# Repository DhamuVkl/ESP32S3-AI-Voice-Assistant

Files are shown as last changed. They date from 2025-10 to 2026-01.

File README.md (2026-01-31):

# Design your own AI voice assistant 






*A fully custom, open-source AI voice assistant powered by ESP32-S3 and Xiaozhi AI framework*

</div>

---

## 📋 Overview

This project is a complete DIY AI voice assistant built around the ESP32-S3 microcontroller. It combines custom PCB design, advanced audio processing, and cloud-based AI to create a device that rivals commercial smart speakers in functionality while remaining fully open-source and customizable.

Unlike simple voice-controlled devices, this assistant leverages the **Xiaozhi AI framework** to provide natural language understanding through large language models (LLMs) like Qwen, DeepSeek, and GPT. The system uses a hybrid architecture: lightweight tasks run locally on the ESP32-S3, while computationally intensive AI processing happens on cloud servers.

### Key Highlights

- ✨ **Natural Conversation**: Powered by modern LLMs for intelligent, context-aware responses
- 🎙️ **Dual-Microphone Array**: Advanced audio capture with beamforming and echo cancellation
- 🔋 **Battery Powered**: Complete power management with USB-C charging and portable operation
- 💡 **WS2812B LED Ring**: Visual feedback with customizable animations
- 🏠 **Smart Home Ready**: Integration with Home Assistant and other platforms
- 🔧 **Fully Customizable**: Open hardware and software for endless possibilities
- 📱 **Web-Based Control**: Easy configuration through Xiaozhi console
- 🌐 **Multi-Language**: Support for multiple languages depending on AI model

---

## 🎯 Features

### Hardware Features
- **ESP32-S3-WROOM-1-N16R8** (Dual-core, 16MB Flash, 8MB PSRAM)
- **Dual ICS-43434 MEMS Microphones** for superior audio capture
- **MAX98357A I²S Amplifier** driving 3W speaker
- **BQ24250 Li-Ion Charger** with USB-C power delivery
- **MAX20402 Buck-Boost Regulator** for stable 3.3V output
- **WS2812B RGB LED Ring** for visual status indication
- **Optional OLED Display** header for screen integration
- **Compact PCB Design** (2-layer, professionally fabricated)
- **Custom 3D-Printed Enclosure** optimized for acoustics

### Software Features
- **Wake Word Detection** using Espressif's WakeNet
- **Audio Front-End (AFE)** with noise reduction and echo cancellation
- **WebSocket Communication** for low-latency server connection
- **Multiple AI Models** (Qwen, DeepSeek, GPT-4, and more)
- **Conversation History** and context awareness
- **Voice Profile Support** for personalized responses
- **Smart Home Integration** via Xiaozhi skill marketplace
- **OTA Updates** for firmware upgrades
- **Battery Monitoring** with low-battery alerts

---

## 🛠️ Hardware

### Bill of Materials (BOM)

| Component | Part Number | Quantity | Notes |
|---|---|---|---|
| Microcontroller | ESP32-S3-WROOM-1-N16R8 | 1 | Main processor |
| Microphones | TDK InvenSense ICS-43434 | 2 | Digital MEMS |
| Audio Amplifier | MAX98357AETE+ | 1 | Class-D I²S |
| Battery Charger | BQ24250RGER | 1 | Li-Ion charging IC |
| DC-DC Converter | MAX20402ATGA/+ | 1 | Buck-boost regulator |
| RGB LEDs | WS2812B-5050 | 8-12 | Addressable LEDs |
| USB-C Connector | USB4105-GF-A | 1 | Power & programming |
| Speaker | 3W 4Ω Cavity Speaker | 1 | Audio output |
| Battery | Li-Ion/LiPo 3.7V | 1 | 2000-3000mAh recommended |
| Capacitors | Various (0603/0805) | ~25 | See full BOM |
| Resistors | Various (0603) | ~15 | See full BOM |
| Switches | 6x6mm Tactile | 2 | Reset & Boot |
| TVS Diode | USBLC6-2SC6 | 1 | USB ESD protection |

**📥 Full BOM with part numbers**: [Download BOM.csv](Hardware/PCB/BOM/ESP-AI-Assistant-BOM.xlsx)

### PCB Design

The custom PCB is a 2-layer design measuring approximately 80x60mm with careful attention to:
- Signal integrity for I²S audio
- Power distribution with minimal noise
- Thermal management for power ICs
- Acoustic isolation between microphones and speaker

### 3D Enclosure

The enclosure is designed for FDM 3D printing with features for:
- Acoustic optimization (speaker grille, microphone ports)
- LED light diffusion ring
- USB-C and button access
- Battery compartment
- Ventilation slots

## 🚀 Getting Started

### Prerequisites

**Hardware Tools**:
- Soldering iron and supplies
- Multimeter for testing
- USB-C cable (data capable)
- 3D printer (optional, for enclosure)

**Software Requirements**:
- [Visual Studio Code](https://code.visualstudio.com/)
- [ESP-IDF Extension for VS Code](https://marketplace.visualstudio.com/items?itemName=espressif.esp-idf-extension)
- ESP-IDF v5.4 or newer
- Git

### Step 1: Hardware Assembly

1. **Order PCB**: Upload `hardware/gerbers/gerbers.zip` to JLCPCB, PCBWay, or ALLPCB
2. **Source Components**: Use the BOM to order parts from DigiKey, Mouser, or LCSC
3. **Assemble PCB**: Follow the assembly guide for soldering instructions
4. **3D Print Enclosure**: Print the STL files and assemble

### Step 2: WiFi Configuration

On first boot, the device creates a WiFi access point:

1. Connect to WiFi network: `Xioazhi`
2. Navigate to `http://192.168.4.1`
3. Enter your WiFi credentials
4. Device will restart and connect to your network

**Alternative**: Configure WiFi via `idf.py menuconfig` before flashing

### Step 3: Xiaozhi Cloud Setup

1. Create account at [xiaozhi.me](https://xiaozhi.me)
2. Navigate to [Console → Agents](https://xiaozhi.me/console/agents)
3. Click "Add Device" to generate Device ID and Pairing Code
4. Device will auto-pair on first cloud connection
5. Customize AI personality, voice, and skills through console

### Step 4: Test Your Assistant

1. Say the wake word: **"Hey Wanda"**
2. Wait for LED confirmation (blue pulse)
3. Speak your question or command
4. Assistant responds through speaker
5. LED returns to idle state

---

## 🤝 Contributing

Contributions are welcome! Here's how you can help:

### Reporting Bugs
- Use GitHub Issues with detailed reproduction steps
- Include serial monitor logs
- Specify hardware revision and firmware version

### Feature Requests
- Open a GitHub Issue with [Feature Request] tag
- Describe use case and benefits
- Discuss implementation approach

**Contribution Guidelines**: [CONTRIBUTING.md](CONTRIBUTING.md)

---

## 📊 Project Status

- [x] PCB Design and fabrication
- [x] Firmware core functionality
- [x] Xiaozhi cloud integration
- [x] Basic voice interaction
- [x] 3D enclosure design
- [ ] Multi-device mesh networking
- [ ] Offline mode with local LLM
- [ ] Custom wake word training tools
- [ ] Mobile app for configuration
- [ ] Additional language packs

---

## 🔗 Related Projects

- [Xiaozhi ESP32](https://github.com/78/xiaozhi-esp32) - Official Xiaozhi firmware
- [ESP-IDF](https://github.com/espressif/esp-idf) - Espressif IoT Development Framework
- [WakeNet](https://github.com/espressif/esp-sr) - Espressif speech recognition
- [Home Assistant](https://www.home-assistant.io/) - Smart home integration

---

## 📄 License

This project is licensed under the MIT License - see [LICENSE](LICENSE) for details.

### Third-Party Licenses
- ESP-IDF: Apache 2.0
- Xiaozhi Framework: MIT
- Component datasheets: Respective manufacturers

---

## 🙏 Acknowledgments

- **Espressif Systems** for the amazing ESP32-S3 platform and development tools
- **Xiaozhi Team** for creating and maintaining the AI framework
- **Open-source community** for countless libraries and examples
- **PCB manufacturers** (JLCPCB, PCBWay) for affordable prototyping
- **Everyone** who contributed feedback, testing, and improvements

---

**Xiaozhi Community**:
- Forum: [xiaozhi.me/community](https://xiaozhi.me/community)
- Documentation: [docs.xiaozhi.me](https://docs.xiaozhi.me)

<div align="center">

**Built with ❤️ by makers, for makers**

[Documentation](docs/) • [Hardware Files](hardware/) • [Firmware](firmware/) • [Community](https://github.com/yourusername/esp32s3-voice-assistant/discussions)

</div>

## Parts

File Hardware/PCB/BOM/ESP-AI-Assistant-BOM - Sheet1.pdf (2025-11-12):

Value | Manufacturer | DigiKey Part Number | DigiKey Link | Datasheet | Quantity
ESP32-S3-WROOM-1-N16R8 | Espressif Systems | 5407-ESP32-S3-WROOM-1-N16R8CT-ND | https://www.digikey.in/short/5rjqc45t | https://www.espressif.com/sites/default/files/documentation/esp32-s3-wroom-1_wroom-1u_datasheet_en.pdf 1
BQ24250RGER | Texas Instruments | 296-43584-1-ND | https://www.digikey.in/short/8w7dh5rt | https://www.ti.com/general/docs/suppproductinfo.tsp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 1
MAX20402AFLB_VY+T | Analog Devices Inc./Maxim Integrated | 175-MAX20402AFLB/VY+TCT-ND | https://www.digikey.in/short/84zhtbjr | https://www.analog.com/media/en/technical-documentation/data-sheets/max20402-max20403.pdf 1
MAX98357AETE+T | Analog Devices Inc./Maxim Integrated | MAX98357AETE+TCT-ND | https://www.digikey.in/short/v0847d0t | https://datasheets.maximintegrated.com/en/ds/MAX98357A-MAX98357B.pdf 1
ICS-43434 | TDK InvenSense | 1428-1066-1-ND | https://www.digikey.in/short/cprbj7jt | https://invensense.tdk.com/download-pdf/ics-43434-datasheet/ | 2
0.1uF | YAGEO | 311-1088-1-ND | https://www.digikey.in/short/j9bbtzmn | https://www.yageo.com/en/Chart/Download/pdf/CC0603KRX7R7BB104 4
1uF | Samsung Electro-Mechanics | 1276-1946-1-ND | https://www.digikey.in/short/w13tfhpm | https://mm.digikey.com/Volume0/opasdata/d220001/medias/docus/3584/CL10B105KP8NNNC_Spec.pdf 8
2.2uF | Samsung Electro-Mechanics | 1276-1040-1-ND | https://www.digikey.in/short/qzm0rdtn | https://mm.digikey.com/Volume0/opasdata/d220001/medias/docus/421/CL10A225KO8NNNC_Spec.pdf 4
10uF | Samsung Electro-Mechanics | 1276-1038-1-ND | https://www.digikey.in/short/7q939fq1 | https://mm.digikey.com/Volume0/opasdata/d220001/medias/docus/609/CL10A106KQ8NNNC_Spec.pdf 1
22uF | Samsung Electro-Mechanics | 1276-1100-1-ND | https://www.digikey.in/short/4z5qrjnc | https://mm.digikey.com/Volume0/opasdata/d220001/medias/docus/5784/CL21A226MQQNNNE.pdf 2
33nF | Samsung Electro-Mechanics | 1276-2040-1-ND | https://www.digikey.in/short/f324pm0d | https://mm.digikey.com/Volume0/opasdata/d220001/medias/docus/1240/CL10B333KB8NFNC_Spec.pdf 1
220pF | KEMET | 399-C0603C221F5GACAUTOCT-ND | https://www.digikey.in/short/tt3r1fv9 | https://search.kemet.com/download/datasheet/C0603C221F5GACAUTO 2
0R | YAGEO | 311-0.0GRCT-ND | https://www.digikey.in/short/b3v7vpzt | https://www.yageogroup.com/content/datasheet/asset/file/PYU-RC_GROUP_51_ROHS_L 4
33R | Stackpole Electronics Inc | RMCF0603FT33R2CT-ND | https://www.digikey.in/short/jp83p589 | https://www.seielect.com/catalog/SEI-RMCF_RMCP.pdf | 2
249R | Stackpole Electronics Inc | RMCF0603FT249RCT-ND | https://www.digikey.in/short/nwpz5jtp | https://www.seielect.com/catalog/SEI-RMCF_RMCP.pdf | 1
267R | YAGEO | 311-267HRCT-ND | https://www.digikey.in/short/w979pjc4 | https://www.yageogroup.com/content/datasheet/asset/file/PYU-RC_GROUP_51_ROHS_L 1
1K | Stackpole Electronics Inc | RMCF0603FT1K00CT-ND | https://www.digikey.in/short/vnptcw85 | https://www.seielect.com/catalog/SEI-RMCF_RMCP.pdf | 2
1K5 | YAGEO | 311-1.5KGRCT-ND | https://www.digikey.in/short/mz5z44p5 | https://www.yageogroup.com/content/datasheet/asset/file/PYU-RC_GROUP_51_ROHS_L 1
5K1 | YAGEO | 311-5.10KHRCT-ND | https://www.digikey.in/short/f454n338 | https://www.yageogroup.com/content/datasheet/asset/file/PYU-RC_GROUP_51_ROHS_L 2
10K | YAGEO | 311-10.0KHRCT-ND | https://www.digikey.in/short/839tmnrn | https://www.yageogroup.com/content/datasheet/asset/file/PYU-RC_GROUP_51_ROHS_L 5
20K | YAGEO | 311-20.0KHRCT-ND | https://www.digikey.in/short/d0d20fp5 | https://www.yageogroup.com/content/datasheet/asset/file/PYU-RC_GROUP_51_ROHS_L 3
100K | Stackpole Electronics Inc | RMCF0603FT100KCT-ND | https://www.digikey.in/short/ph19q045 | https://www.seielect.com/catalog/SEI-RMCF_RMCP.pdf | 2
274K | Stackpole Electronics Inc | RMCF0603FT274KCT-ND | https://www.digikey.in/short/d8vrz4zz | https://www.seielect.com/catalog/SEI-RMCF_RMCP.pdf | 1
1uH | TDK Corporation | 445-6672-1-ND | https://www.digikey.in/short/hqtv9tb5 | https://mm.digikey.com/Volume0/opasdata/d220001/medias/docus/2091/VLS3015E_Series.pdf 1
1.5uH | Taiyo Yuden | 587-2617-1-ND | https://www.digikey.in/short/4rtp9mqb | https://mm.digikey.com/Volume0/opasdata/d220001/medias/docus/610/NR3015T1R5N_SS.pdf 1
FerriteBead_Small | Eaton - Electronics Division | 283-MFBW1V2012-000-RCT-ND | https://www.digikey.in/short/v80fpmrb | https://www.eaton.com/content/dam/eaton/products/electronic-components/resources/data-sheet/eaton-mfbw1v2012-high-impedance-multilayer-ferrite-chip-bead-data-sheet.p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 2
SLW-66527511-SMT-TR | Same Sky (Formerly CUI Devices) | 2223-SLW-66527511-SMT-TRCT-ND | https://www.digikey.in/short/04nz77qw | https://www.cuidevices.com/product/resource/digikeypdf/slw-66527511-smt-tr.pdf 2
WS2812B RGB LED | XINGLIGHT | 5962-XL-5050RGBC-WS2812BTR-ND | https://www.digikey.in/short/mt8f2cfr | https://mm.digikey.com/Volume0/opasdata/d220001/medias/docus/6472/5962_XL-5050RGBC-WS2812B%20%205050%E5%B9%BB%E5%BD%A9%E9%80%8F%E6%98%8E.pdf 4
LED Red | XINGLIGHT | 5962-XL-1608SURC-06TR-ND | https://www.digikey.in/short/95jnwpf4 | https://mm.digikey.com/Volume0/opasdata/d220001/medias/docus/6472/5962_XL-1608SURC-06%20%20%200603%E7%BA%A20.6T.pdf 1
LED Blue | XINGLIGHT | 5962-XL-1608UBC-04TR-ND | https://www.digikey.in/short/2zmhjvv8 | https://mm.digikey.com/Volume0/opasdata/d220001/medias/docus/6472/5962_XL-1608UBC-04%20%20%200603%E8%93%9D0.4T.pdf 1
Tactile Switch SPST | Omron Electronics Inc-EMC Div | SW1021CT-ND | https://www.digikey.in/short/czjddfbv | https://omronfs.omron.com/en_US/ecb/products/pdf/en-b3u.pdf 2
USB_C Receptacle | GCT | 2073-USB4105-GF-A-060CT-ND | https://www.digikey.in/short/4vnp0cm8 | https://gct.co/files/specs/usb4105-spec.pdf | 1
B2B-PH-K-S | JST Sales America Inc. | 455-1704-ND | https://www.digikey.in/short/793pddq3 | https://www.jst-mfg.com/product/pdf/eng/ePH.pdf | 2
Conn_01x08 | Adam Tech | 2057-2SH-C-08-TS-ND | https://www.digikey.in/short/4q5zwphp | https://app.adam-tech.com/products/download/data_sheet/240572/2sh-c-xx-ts-data-sheet.pdf 1

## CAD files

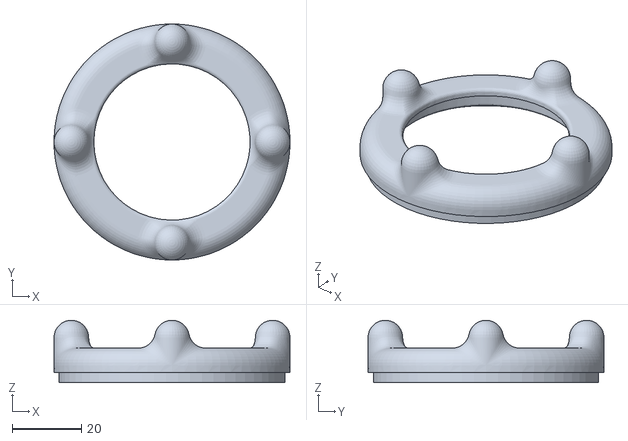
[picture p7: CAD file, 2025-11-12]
Hardware/CAD/Bottom-Enclosure.STL
68.0 x 68.0 x 18.0

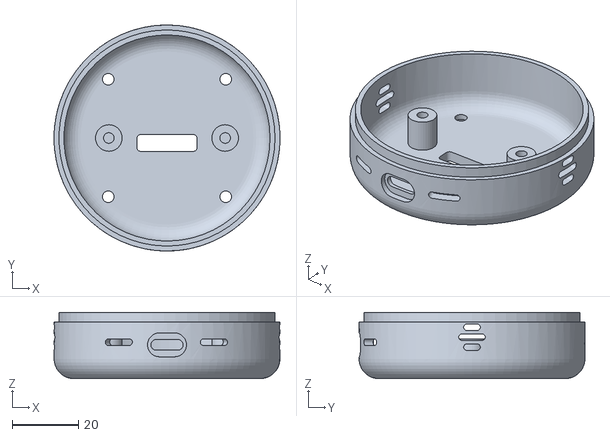
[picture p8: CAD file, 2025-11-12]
Hardware/CAD/Top-Enclosure-Cap.STL
68.0 x 68.0 x 20.0

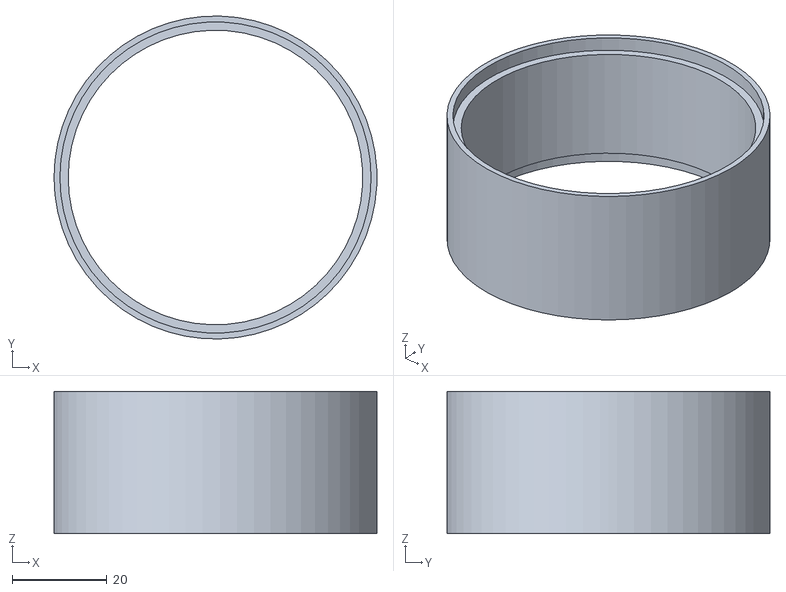
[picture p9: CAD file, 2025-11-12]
Hardware/CAD/Middle-Enclosure.STL
68.0 x 68.0 x 30.0

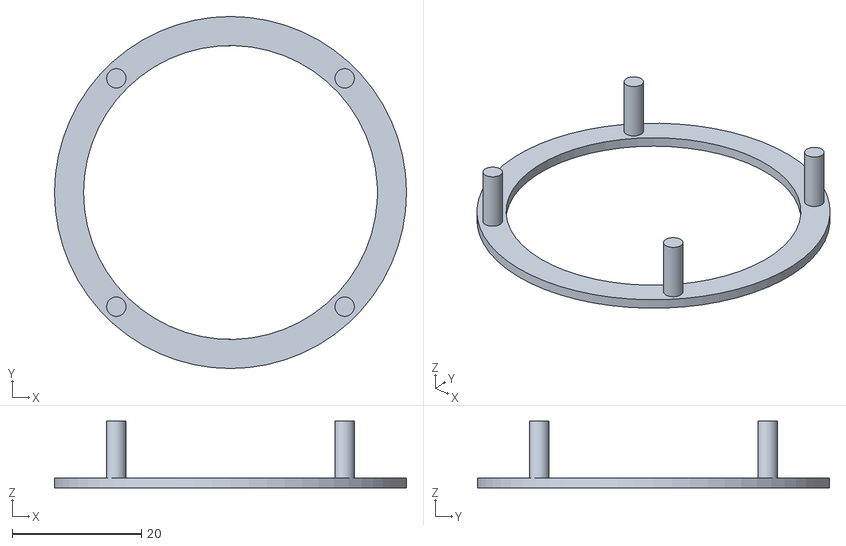
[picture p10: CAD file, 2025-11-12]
Hardware/CAD/Neopixel-Diffuser-Ring.STL
54.5 x 54.5 x 10.3

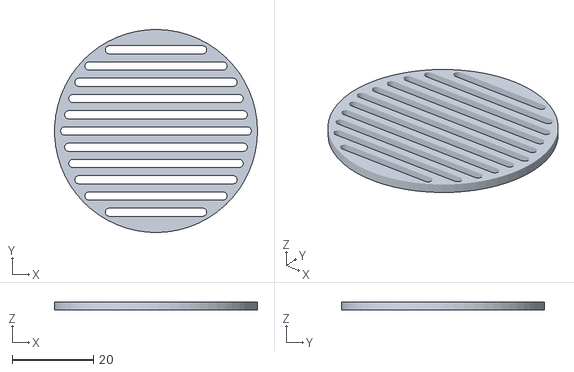
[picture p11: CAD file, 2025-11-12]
Hardware/CAD/Speaker-grill.STL
50.0 x 50.0 x 2.00

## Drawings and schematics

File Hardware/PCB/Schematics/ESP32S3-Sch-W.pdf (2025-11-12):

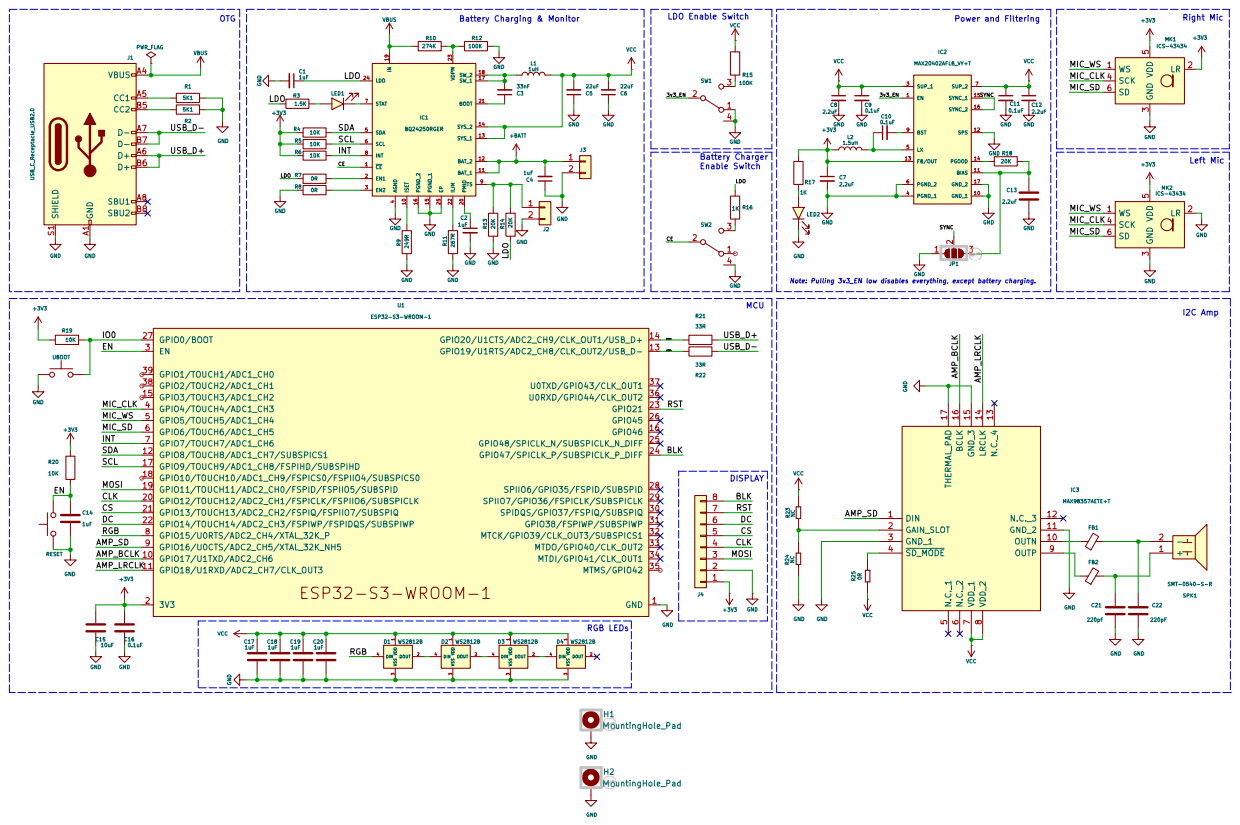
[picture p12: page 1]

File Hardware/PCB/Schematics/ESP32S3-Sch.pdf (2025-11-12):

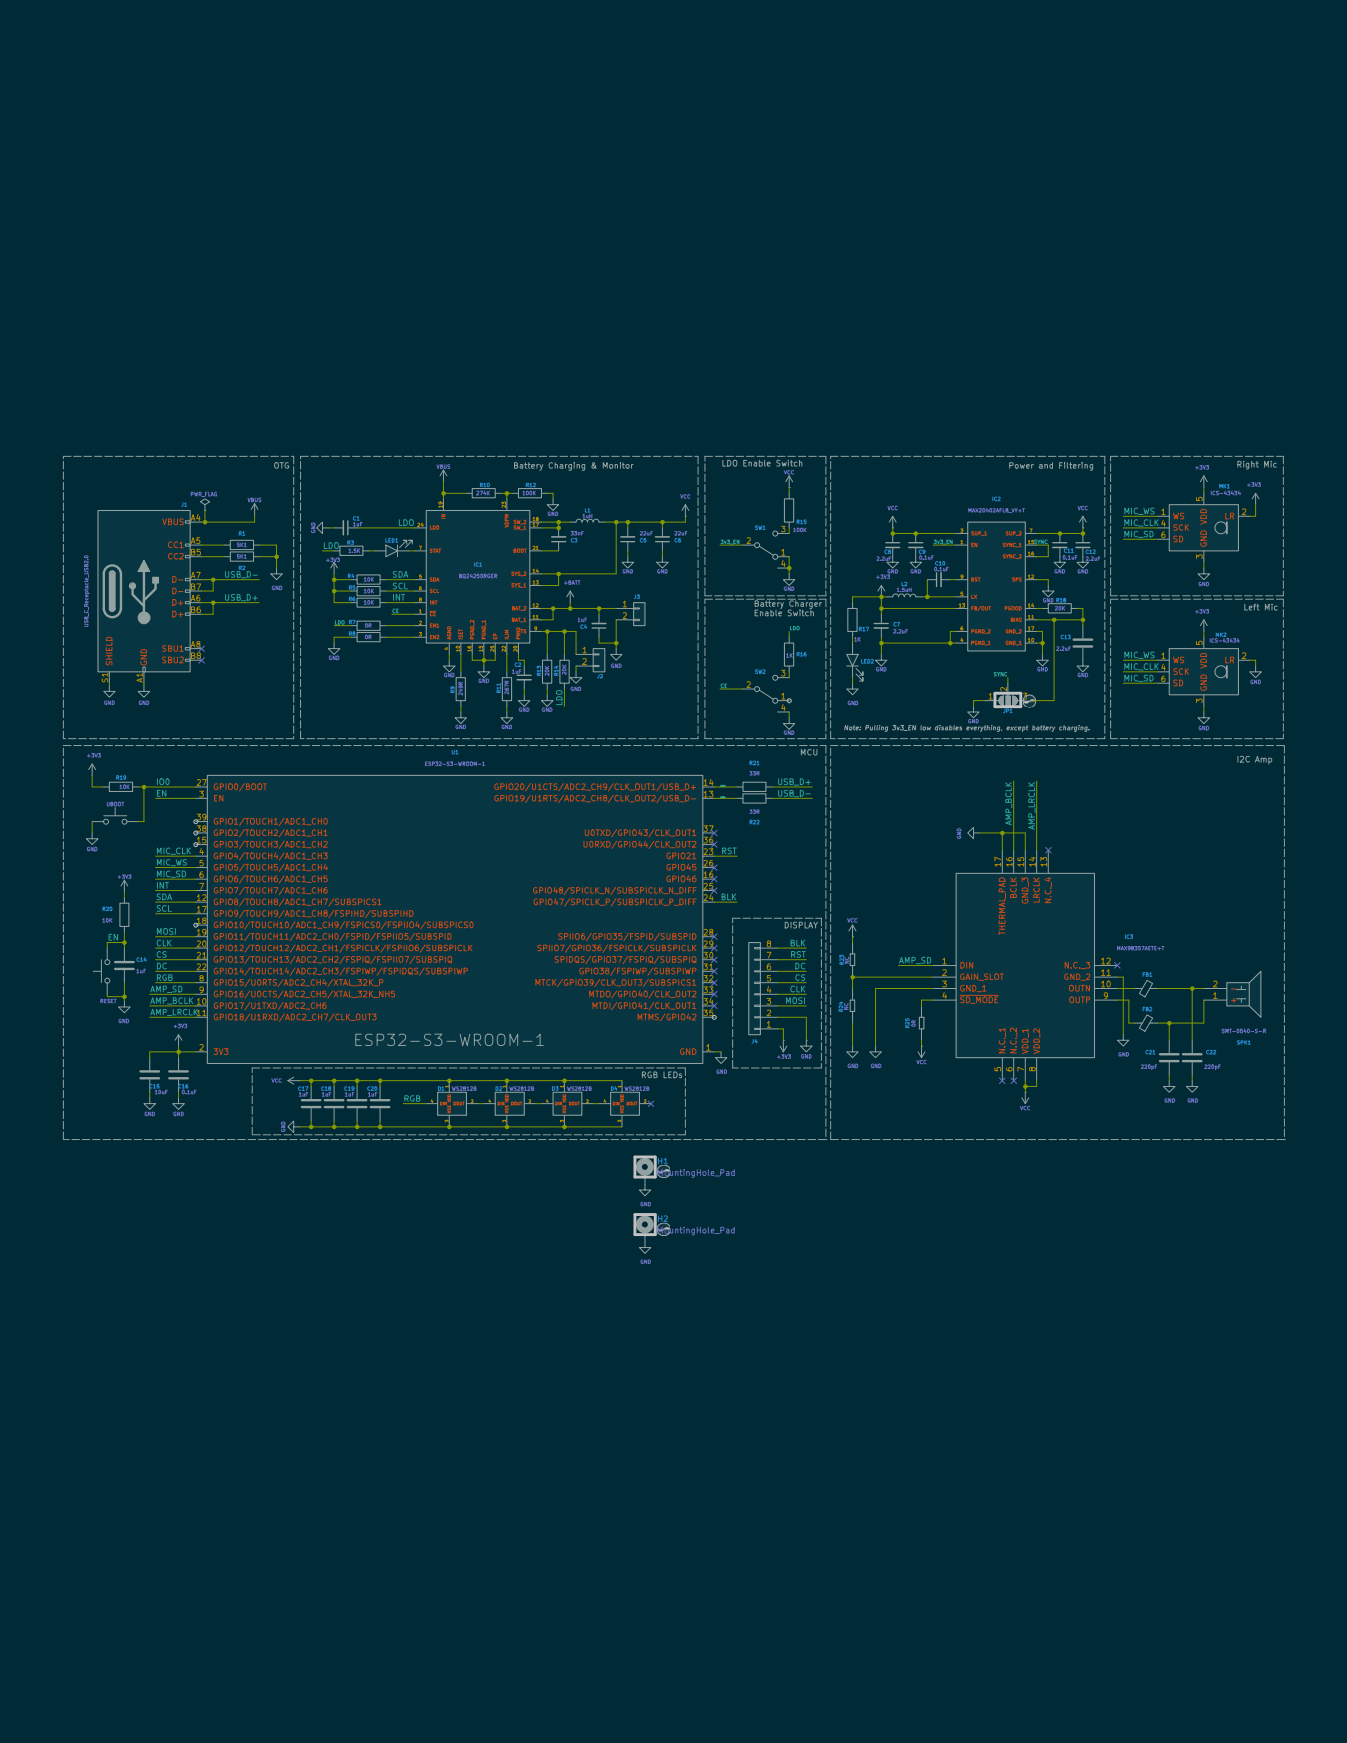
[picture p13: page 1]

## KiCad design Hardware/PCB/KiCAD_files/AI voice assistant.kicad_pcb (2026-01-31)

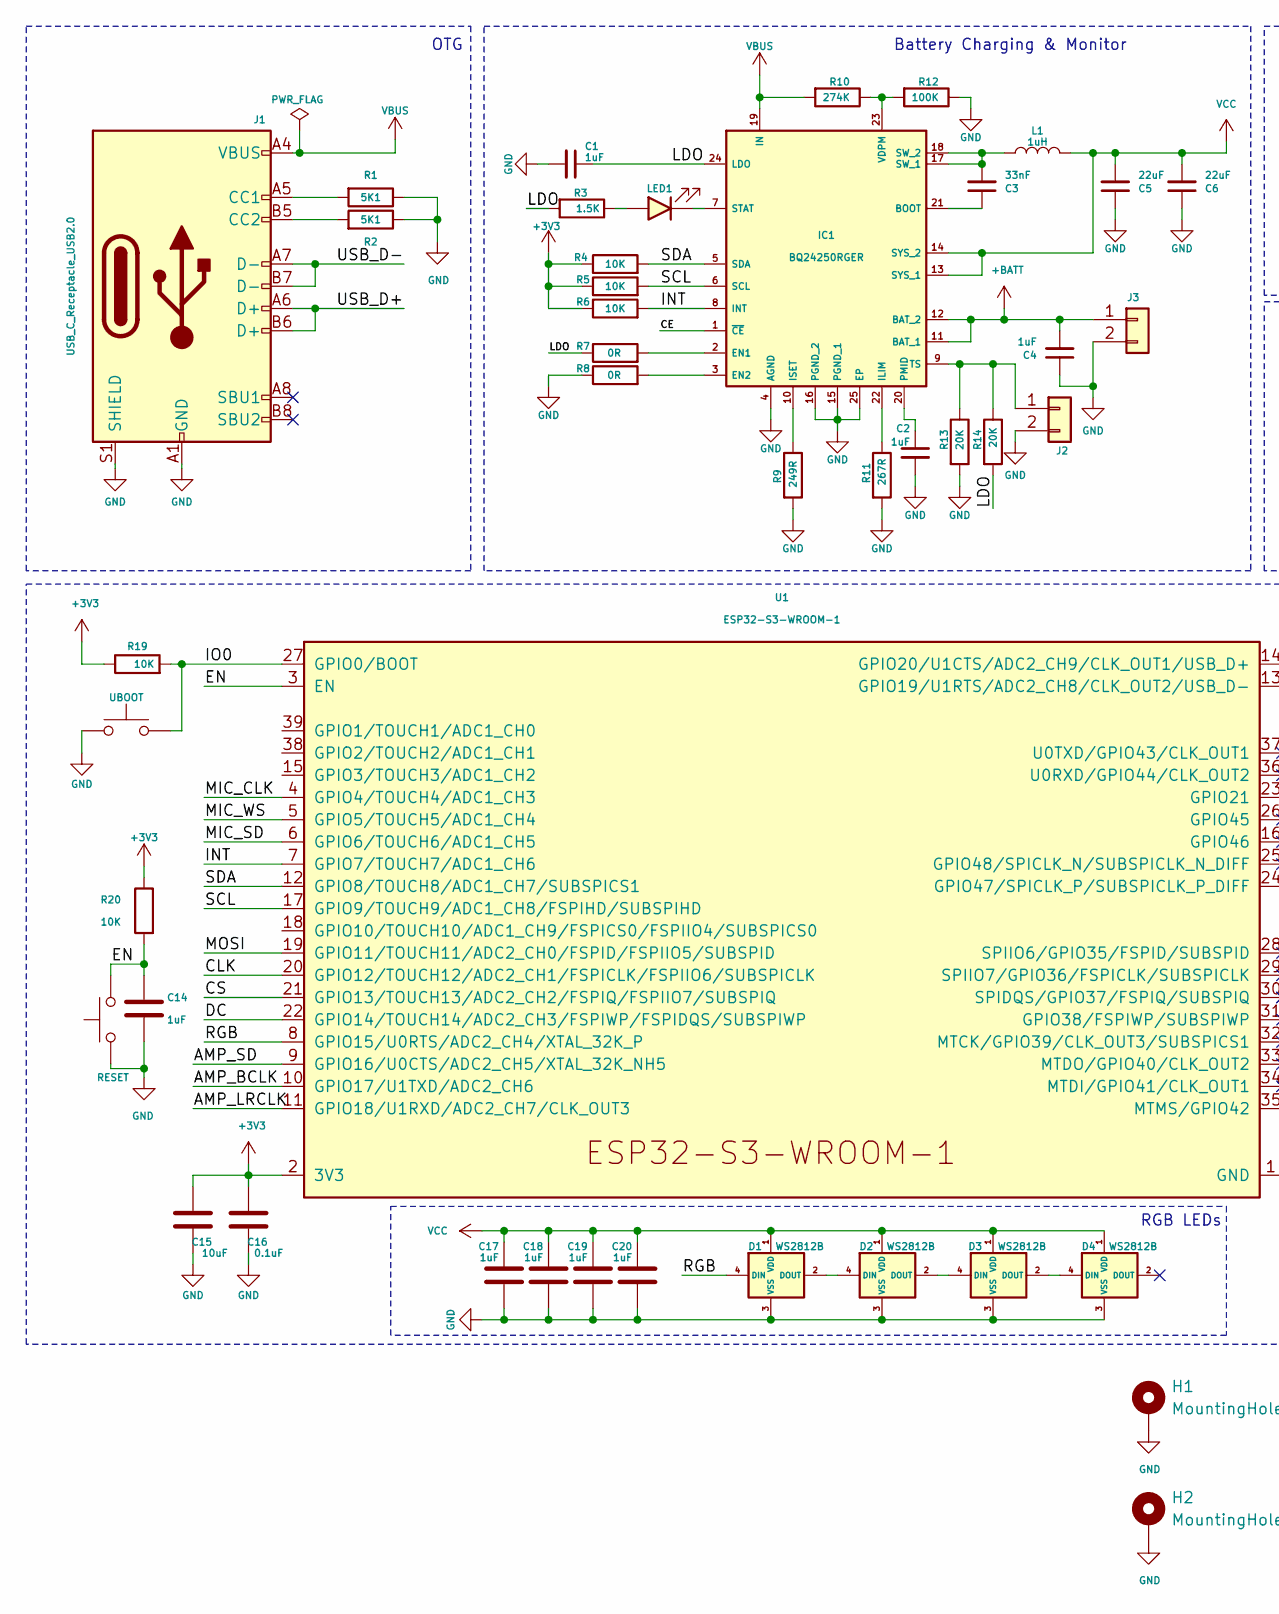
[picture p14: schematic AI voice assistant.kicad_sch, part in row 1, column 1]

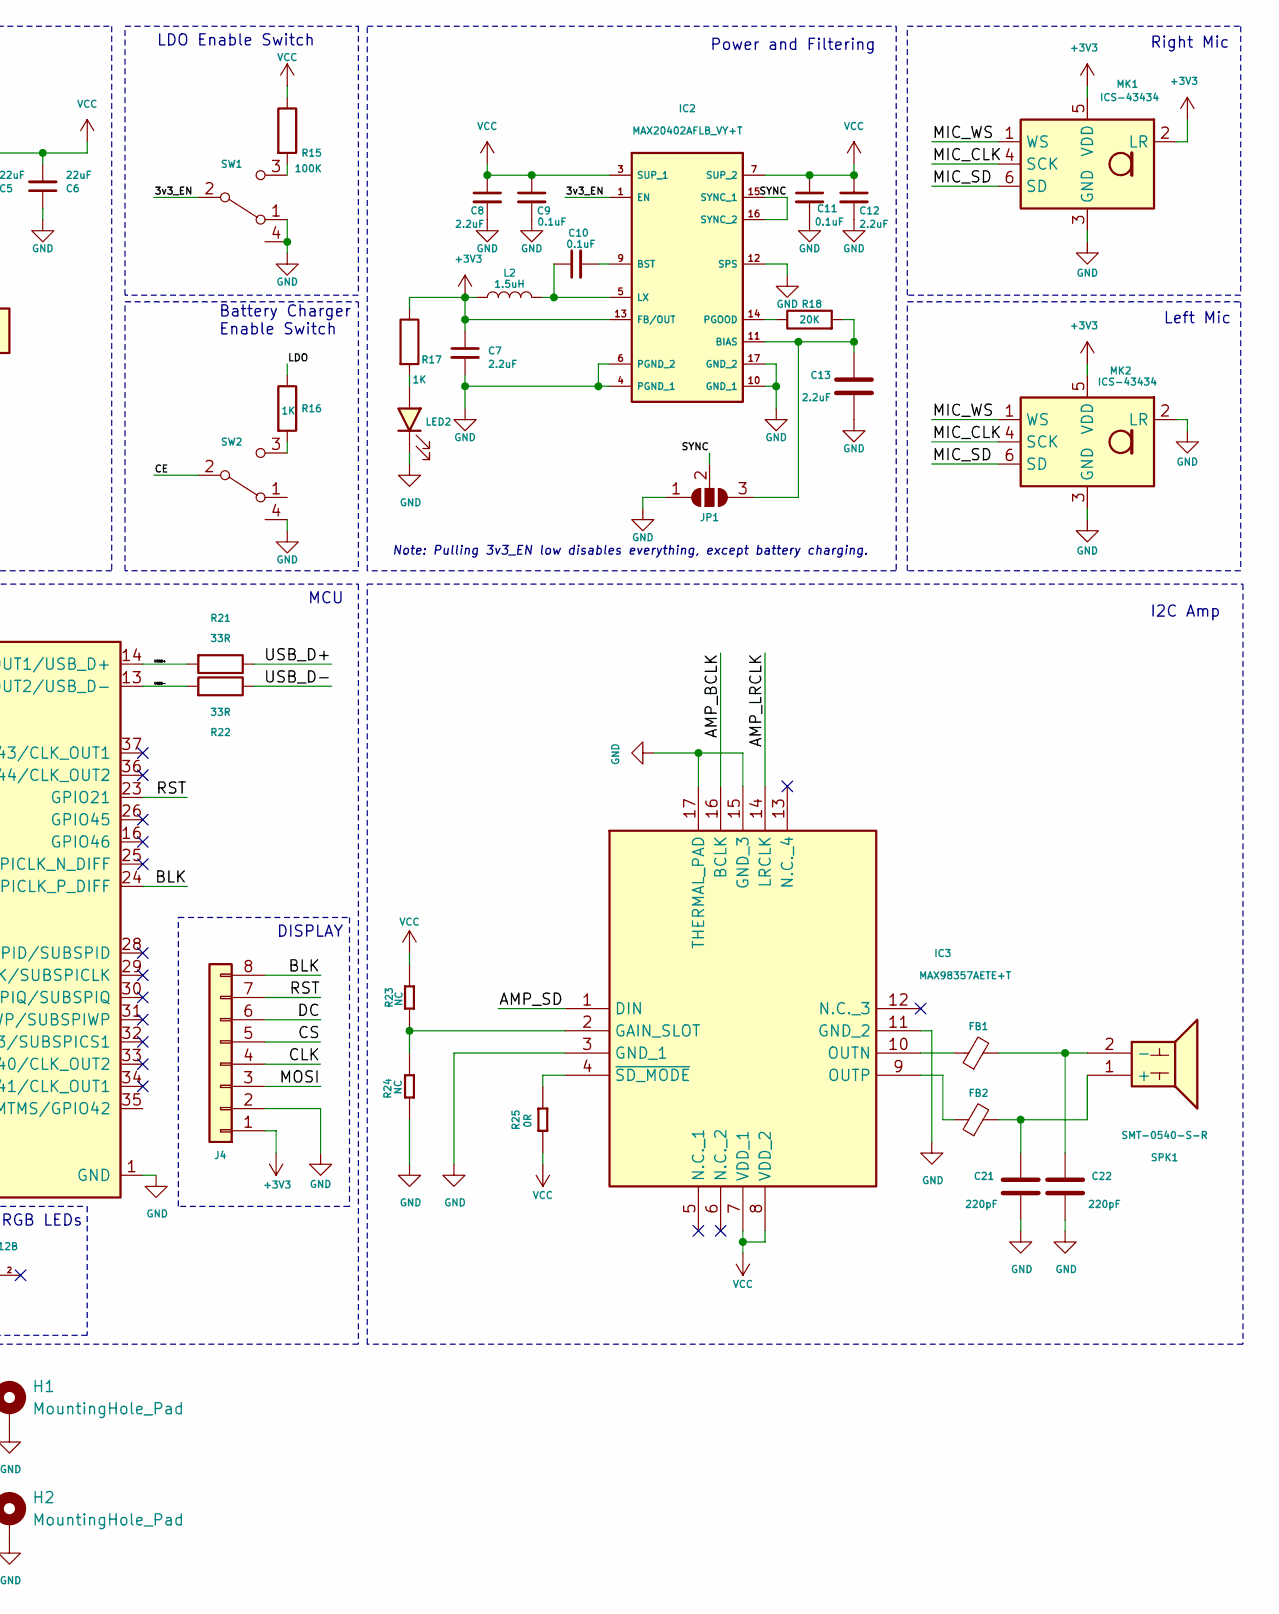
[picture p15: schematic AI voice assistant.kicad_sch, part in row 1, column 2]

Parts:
BOOT1: RESET; Tactile 3x4x2mm TS-A010; DigiKey Part Number 2449-CS1213AGF160CT-ND
BOOT2: UBOOT; Tactile 3x4x2mm TS-A010; DigiKey Part Number 2449-CS1213AGF160CT-ND
C1, C2, C4: 1uF; C_0603_1608Metric
C3: 33nF; C_0603_1608Metric
C5, C6: 22uF; C_0805_2012Metric
C7, C8, C12: 2.2uF; C_0603_1608Metric
C9, C10, C11: 0.1uF; C_0603_1608Metric
C13: 2.2uF; C_0603_1608Metric; DigiKey Part Number 490-6328-1-ND
C14, C17, C18, C19, C20: 1uF; C_0603_1608Metric; DigiKey Part Number 490-6328-1-ND
C15: 10uF; C_0603_1608Metric; DigiKey Part Number 490-6328-1-ND
C16: 0.1uF; C_0603_1608Metric; DigiKey Part Number 490-6328-1-ND
C21, C22: 220pF; C_0603_1608Metric; DigiKey Part Number 490-10018-1-ND
D1, D2, D3, D4: WS2812B; LED_WS2812B_PLCC4_5.0x5.0mm_P3.2mm
FB1, FB2: FerriteBead_Small; L_0805_2012Metric
H1, H2: MountingHole_Pad; MountingHole_2.7mm_M2.5_DIN965_Pad
IC1: BQ24250RGER; QFN50P400X400X100-25N-D; Mouser Part Number 595-BQ24250RGER
IC2: MAX20402AFLB_VY+T; MAX20402AFLBVYT; Mouser Part Number 700-MAX20402AFLBVY+T
IC3: MAX98357AETE+T; QFN50P300X300X80-17N; Mouser Part Number 700-MAX98357AETE+T
J1: USB_C_Receptacle_USB2.0; USB_C_Receptacle_XKB_U262-16XN-4BVC11; DigiKey Part Number 2073-USB4105-GF-ACT-ND
J2, J3: B2B-PH-SM4-TB(LF)(SN); JST_PH_B2B-PH-K_1x02_P2.00mm_Vertical; DigiKey Part Number 455-1704-ND
J4: Conn_01x08; JST_PH_B8B-PH-K_1x08_P2.00mm_Vertical
JP1: SolderJumper_3_Open; SolderJumper-3_P2.0mm_Open_TrianglePad1.0x1.5mm
L1: 1uH; L_Cenker_CKCS6045
L2: 1.5uH; L_Cenker_CKCS5020
LED1, LED2: LED Red; LED_0603_1608Metric; DigiKey Part Number 3147-B1911USD-20D000114U1930CT-ND
MK1, MK2: ICS-43434; InvenSense_ICS-43434-6_3.5x2.65mm
R1, R2: 5K1; R_0603_1608Metric; DigiKey Part Number P5.10KHCT-ND
R3: 1.5K; R_0603_1608Metric; DigiKey Part Number P1.00KHCT-ND
R4, R5, R6: 10K; R_0603_1608Metric; DigiKey Part Number P1.00KHCT-ND
R7, R8: 0R; R_0603_1608Metric; DigiKey Part Number P1.00KHCT-ND
R9: 249R; R_0603_1608Metric; DigiKey Part Number P1.00KHCT-ND
R10: 274K; R_0603_1608Metric; DigiKey Part Number P1.00KHCT-ND
R11: 267R; R_0603_1608Metric; DigiKey Part Number P1.00KHCT-ND
R12: 100K; R_0603_1608Metric; DigiKey Part Number P1.00KHCT-ND
R13, R14, R18: 20K; R_0603_1608Metric; DigiKey Part Number P1.00KHCT-ND
R15: 100K; R_0603_1608Metric; DigiKey Part Number P100KHCT-ND
R16: 1K; R_0603_1608Metric; DigiKey Part Number P100KHCT-ND
R17: 1K; R_0603_1608Metric; DigiKey Part Number P1.00KHCT-ND
R19, R20: 10K; R_0603_1608Metric; DigiKey Part Number P10.0KHCT-ND
R21, R22: 33R; R_0603_1608Metric; DigiKey Part Number P17467CT-ND
R23, R24: NC; R_0603_1608Metric
R25: 0R; R_0603_1608Metric
SPK1: SMT-0540-S-R; JST_PH_B2B-PH-K_1x02_P2.00mm_Vertical; Manufacturer_Part_Number SMT-0540-S-R; DigiKey Part Number 668-1060-1-ND
SW1, SW2: SLW-66527511-SMT-TR; slide switch spdt; DigiKey Part Number 2223-SLW-66527511-SMT-TRCT-ND
U1: ESP32-S3-WROOM-1; DigiKey Part Number 1965-ESP32-S3-WROOM-1-N16R8CT-ND

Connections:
+3V3: C7.1, C15.1, C16.1, IC2.13 (FB/OUT), J4.1, L2.1, MK1.2 (LR), MK1.5 (VDD), MK2.5 (VDD), R4.1, R5.1, R6.1, R17.1, R19.1, R20.1, U1.2 (3V3)
+BATT: C4.2, IC1.11 (BAT_1), IC1.12 (BAT_2), J3.1
/3v3_EN: IC2.1 (EN), SW1.2 (B)
/AMP_BCLK: IC3.16 (BCLK), U1.10 (GPIO17/U1TXD/ADC2_CH6)
/AMP_LRCLK: IC3.14 (LRCLK), U1.11 (GPIO18/U1RXD/ADC2_CH7/CLK_OUT3)
/AMP_SD: IC3.1 (DIN), U1.9 (GPIO16/U0CTS/ADC2_CH5/XTAL_32K_NH5)
/BLK: J4.8, U1.24 (GPIO47/SPICLK_P/SUBSPICLK_P_DIFF)
/CE: IC1.1 (~CE), SW2.2 (B)
/CLK: J4.4, U1.20 (GPIO12/TOUCH12/ADC2_CH1/FSPICLK/FSPIIO6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)
/CS: J4.5, U1.21 (GPIO13/TOUCH13/ADC2_CH2/FSPIQ/FSPIIO7/S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)
/DC: J4.6, U1.22 (GPIO14/TOUCH14/ADC2_CH3/FSPIWP/FSPIDQS/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)
/EN: BOOT1.1, C14.1, R20.2, U1.3 (EN)
/INT: IC1.8 (INT), R6.2, U1.7 (GPIO7/TOUCH7/ADC1_CH6)
/IO0: BOOT2.1, R19.2, U1.27 (GPIO0/BOOT)
/LDO: C1.1, IC1.24 (LDO), R3.2, R7.1, R14.2, R16.1
/MIC_CLK: MK1.4 (SCK), MK2.4 (SCK), U1.4 (GPIO4/TOUCH4/ADC1_CH3)
/MIC_SD: MK1.6 (SD), MK2.6 (SD), U1.6 (GPIO6/TOUCH6/ADC1_CH5)
/MIC_WS: MK1.1 (WS), MK2.1 (WS), U1.5 (GPIO5/TOUCH5/ADC1_CH4)
/MOSI: J4.3, U1.19 (GPIO11/TOUCH11/ADC2_CH0/FSPID/FSPIIO5/S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)
/RGB: D1.4 (DIN), U1.8 (GPIO15/U0RTS/ADC2_CH4/XTAL_32K_P)
/RST: J4.7, U1.23 (GPIO21)
/SCL: IC1.6 (SCL), R5.2, U1.17 (GPIO9/TOUCH9/ADC1_CH8/FSPIHD/SUBSPIHD)
/SDA: IC1.5 (SDA), R4.2, U1.12 (GPIO8/TOUCH8/ADC1_CH7/SUBSPICS1)
/SYNC: IC2.15 (SYNC_1), IC2.16 (SYNC_2), JP1.2 (C)
/USBD+: R21.2, U1.14 (GPIO20/U1CTS/ADC2_CH9/CLK_OUT1/USB_D+)
/USBD-: R22.2, U1.13 (GPIO19/U1RTS/ADC2_CH8/CLK_OUT2/USB_D-)
/USB_D+: J1.A6 (D+), J1.B6 (D+), R21.1
/USB_D-: J1.A7 (D-), J1.B7 (D-), R22.1
GND: BOOT1.2, BOOT2.2, C1.2, C2.2, C4.1, C5.1, C6.1, C7.2, C8.2, C9.2, C11.2, C12.2, C13.2, C14.2, C15.2, C16.2, C17.2, C18.2, C19.2, C20.2, C21.2, C22.2, D1.3 (VSS), D2.3 (VSS), D3.3 (VSS), D4.3 (VSS), H1.1, H2.1, IC1.4 (AGND), IC1.15 (PGND_1), IC1.16 (PGND_2), IC1.25 (EP), IC2.4 (PGND_1), IC2.6 (PGND_2), IC2.10 (GND_1), IC2.12 (SPS), IC2.17 (GND_2), IC3.3 (GND_1), IC3.11 (GND_2), IC3.15 (GND_3), IC3.17 (THERMAL_PAD), J1.A1 (GND), J1.A12 (GND), J1.B1 (GND), J1.B12 (GND), J1.S1 (SHIELD), J2.2, J3.2, J4.2, JP1.1 (A), LED2.1 (K), MK1.3 (GND), MK2.2 (LR), MK2.3 (GND), R1.1, R2.1, R8.1, R9.2, R11.2, R12.1, R13.2, R24.1, SW1.1 (A), SW1.4, SW2.4, U1.1 (GND), U1.40 (GND), U1.41 (GND)
unnamed: D1.2 (DOUT), D2.4 (DIN)
unnamed: D2.2 (DOUT), D3.4 (DIN)
unnamed: D3.2 (DOUT), D4.4 (DIN)
unnamed: C3.1, IC1.21 (BOOT)
unnamed: IC1.2 (EN1), R7.2
unnamed: IC1.3 (EN2), R8.2
unnamed: IC1.22 (ILIM), R11.1
unnamed: IC1.10 (ISET), R9.1
unnamed: C2.1, IC1.20 (PMID)
unnamed: IC1.7 (STAT), LED1.1 (K)
unnamed: C3.2, IC1.17 (SW_1), IC1.18 (SW_2), L1.1
unnamed: IC1.9 (TS), J2.1, R13.1, R14.1
unnamed: IC1.23 (VDPM), R10.1, R12.2
unnamed: C13.1, IC2.11 (BIAS), JP1.3 (B), R18.2
unnamed: C10.2, IC2.9 (BST)
unnamed: C10.1, IC2.5 (LX), L2.2
unnamed: IC2.2 (NC_1), IC2.8 (NC_2)
unnamed: IC2.14 (PGOOD), R18.1
unnamed: IC3.2 (GAIN_SLOT), R23.2, R24.2
unnamed: FB1.1, IC3.10 (OUTN)
unnamed: FB2.1, IC3.9 (OUTP)
unnamed: IC3.4 (~SD_MODE), R25.1
unnamed: J1.A5 (CC1), R1.2
unnamed: J1.B5 (CC2), R2.2
unnamed: LED1.2 (A), R3.1
unnamed: LED2.2 (A), R17.2
unnamed: C21.1, FB2.2, SPK1.1 (+)
unnamed: C22.1, FB1.2, SPK1.2 (-)
unnamed: R15.2, SW1.3 (C)
unnamed: R16.2, SW2.3 (C)
VBUS: IC1.19 (IN), J1.A4 (VBUS), J1.A9 (VBUS), J1.B4 (VBUS), J1.B9 (VBUS), R10.2
VCC: C5.2, C6.2, C8.1, C9.1, C11.1, C12.1, C17.1, C18.1, C19.1, C20.1, D1.1 (VDD), D2.1 (VDD), D3.1 (VDD), D4.1 (VDD), IC1.13 (SYS_1), IC1.14 (SYS_2), IC2.3 (SUP_1), IC2.7 (SUP_2), IC3.7 (VDD_1), IC3.8 (VDD_2), L1.2, R15.1, R23.1, R25.2

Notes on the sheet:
I2C Amp
LDO Enable Switch
Right Mic
Battery Charger Enable Switch
Left Mic
DISPLAY
Note: Pulling 3v3_EN low disables everything, except battery charging.
Power and Filtering
Battery Charging & Monitor
OTG
RGB LEDs
MCU

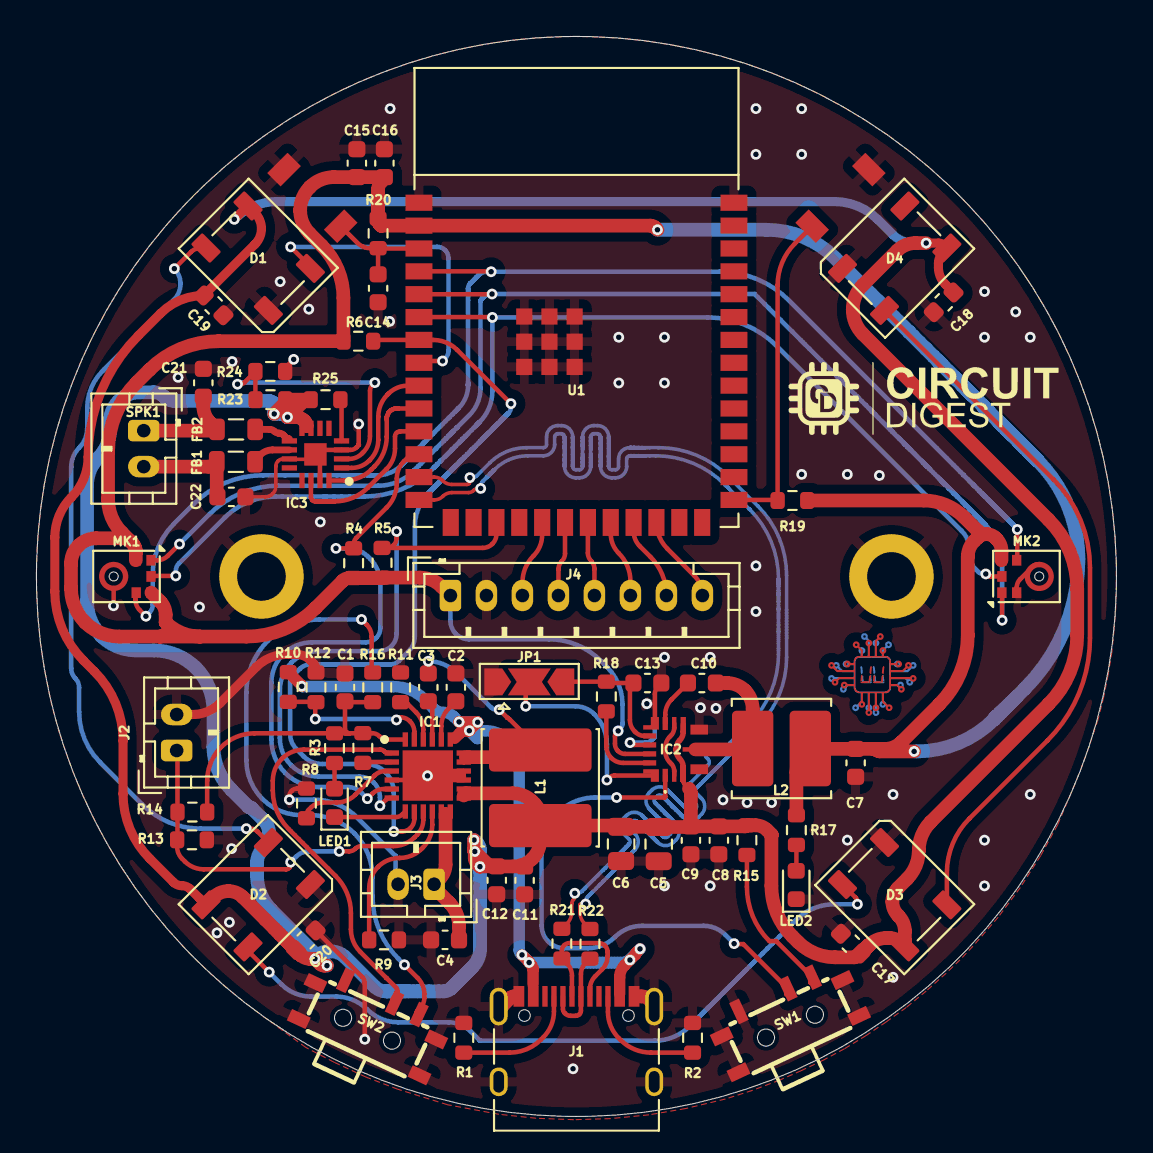
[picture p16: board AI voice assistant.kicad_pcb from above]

Board: 2 copper layers, 60.0 x 60.0 mm, 75 parts (0 on the bottom side), 61 nets.

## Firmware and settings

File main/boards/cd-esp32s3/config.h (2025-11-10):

#ifndef _BOARD_CONFIG_H_
#define _BOARD_CONFIG_H_

#include <driver/gpio.h>

#define AUDIO_INPUT_SAMPLE_RATE 24000
#define AUDIO_OUTPUT_SAMPLE_RATE 24000 // Increased sample rate

//  Duplex I2S
#define AUDIO_I2S_METHOD_SIMPLEX

#ifdef AUDIO_I2S_METHOD_SIMPLEX

#define AUDIO_I2S_MIC_GPIO_WS GPIO_NUM_5
#define AUDIO_I2S_MIC_GPIO_SCK GPIO_NUM_4
#define AUDIO_I2S_MIC_GPIO_DIN GPIO_NUM_6
#define AUDIO_I2S_SPK_GPIO_DOUT GPIO_NUM_16
#define AUDIO_I2S_SPK_GPIO_BCLK GPIO_NUM_17
#define AUDIO_I2S_SPK_GPIO_LRCK GPIO_NUM_18

#else

#define AUDIO_I2S_GPIO_WS GPIO_NUM_4
#define AUDIO_I2S_GPIO_BCLK GPIO_NUM_5
#define AUDIO_I2S_GPIO_DIN GPIO_NUM_6
#define AUDIO_I2S_GPIO_DOUT GPIO_NUM_7

#endif

#define BUILTIN_LED_GPIO GPIO_NUM_15
#define BOOT_BUTTON_GPIO GPIO_NUM_0
#define TOUCH_BUTTON_GPIO GPIO_NUM_3
#define VOLUME_UP_BUTTON_GPIO GPIO_NUM_47
#define VOLUME_DOWN_BUTTON_GPIO GPIO_NUM_48

#define DISPLAY_SDA_PIN GPIO_NUM_40
#define DISPLAY_SCL_PIN GPIO_NUM_41
#define DISPLAY_WIDTH 128

#if CONFIG_OLED_SSD1306_128X32
#define DISPLAY_HEIGHT 32
#elif CONFIG_OLED_SSD1306_128X64
#define DISPLAY_HEIGHT 64
#elif CONFIG_OLED_SH1106_128X64
#define DISPLAY_HEIGHT 64
#define SH1106
#else
#error " OLED "
#endif

#define DISPLAY_MIRROR_X true
#define DISPLAY_MIRROR_Y true

// A MCP Test: Control a lamp
#define LAMP_GPIO GPIO_NUM_13

// Traffic Light LEDs: Control 3 LEDs
#define RED_LED_GPIO GPIO_NUM_11
#define YELLOW_LED_GPIO GPIO_NUM_12
#define GREEN_LED_GPIO GPIO_NUM_14

#endif // _BOARD_CONFIG_H_

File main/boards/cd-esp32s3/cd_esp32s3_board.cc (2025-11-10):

#include "wifi_board.h"
#include "codecs/no_audio_codec.h"
#include "display/oled_display.h"
#include "system_reset.h"
#include "application.h"
#include "button.h"
#include "config.h"
#include "mcp_server.h"
#include "lamp_controller.h"
#include "traffic_light_controller.h"
#include "led/circular_strip.h"
#include "assets/lang_config.h"

#include <wifi_station.h>
#include <esp_log.h>
#include <driver/i2c_master.h>
#include <esp_lcd_panel_ops.h>
#include <esp_lcd_panel_vendor.h>

#ifdef SH1106
#include <esp_lcd_panel_sh1106.h>
#endif

#define TAG "CompactWifiBoard"

class CompactWifiBoard : public WifiBoard
{
private:
    i2c_master_bus_handle_t display_i2c_bus_;
    esp_lcd_panel_io_handle_t panel_io_ = nullptr;
    esp_lcd_panel_handle_t panel_ = nullptr;
    Display *display_ = nullptr;
    Button boot_button_;
    Button touch_button_;
    Button volume_up_button_;
    Button volume_down_button_;
    CircularStrip *led_strip_ = nullptr;
    void InitializeDisplayI2c()
    {
        i2c_master_bus_config_t bus_config = {
            .i2c_port = (i2c_port_t)0,
            .sda_io_num = DISPLAY_SDA_PIN,
            .scl_io_num = DISPLAY_SCL_PIN,
            .clk_source = I2C_CLK_SRC_DEFAULT,
            .glitch_ignore_cnt = 7,
            .intr_priority = 0,
            .trans_queue_depth = 0,
            .flags = {
                .enable_internal_pullup = 1,
            },
        };
        ESP_ERROR_CHECK(i2c_new_master_bus(&bus_config, &display_i2c_bus_));
    }

    void InitializeSsd1306Display()
    {
        // SSD1306 config
        esp_lcd_panel_io_i2c_config_t io_config = {
            .dev_addr = 0x3C,
            .on_color_trans_done = nullptr,
            .user_ctx = nullptr,
            .control_phase_bytes = 1,
            .dc_bit_offset = 6,
            .lcd_cmd_bits = 8,
            .lcd_param_bits = 8,
            .flags = {
                .dc_low_on_data = 0,
                .disable_control_phase = 0,
            },
            .scl_speed_hz = 400 * 1000,
        };

        ESP_ERROR_CHECK(esp_lcd_new_panel_io_i2c_v2(display_i2c_bus_, &io_config, &panel_io_));

        ESP_LOGI(TAG, "Install SSD1306 driver");
        esp_lcd_panel_dev_config_t panel_config = {};
        panel_config.reset_gpio_num = -1;
        panel_config.bits_per_pixel = 1;

        esp_lcd_panel_ssd1306_config_t ssd1306_config = {
            .height = static_cast<uint8_t>(DISPLAY_HEIGHT),
        };
        panel_config.vendor_config = &ssd1306_config;

#ifdef SH1106
        ESP_ERROR_CHECK(esp_lcd_new_panel_sh1106(panel_io_, &panel_config, &panel_));
#else
        ESP_ERROR_CHECK(esp_lcd_new_panel_ssd1306(panel_io_, &panel_config, &panel_));
#endif
        ESP_LOGI(TAG, "SSD1306 driver installed");

        // Reset the display
        ESP_ERROR_CHECK(esp_lcd_panel_reset(panel_));
        if (esp_lcd_panel_init(panel_) != ESP_OK)
        {
            ESP_LOGE(TAG, "Failed to initialize display");
            display_ = new NoDisplay();
            return;
        }
        ESP_ERROR_CHECK(esp_lcd_panel_invert_color(panel_, false));

        // Set the display to on
        ESP_LOGI(TAG, "Turning display on");
        ESP_ERROR_CHECK(esp_lcd_panel_disp_on_off(panel_, true));

        display_ = new OledDisplay(panel_io_, panel_, DISPLAY_WIDTH, DISPLAY_HEIGHT, DISPLAY_MIRROR_X, DISPLAY_MIRROR_Y);
    }

    void InitializeButtons()
    {
        boot_button_.OnClick([this]()
                             {
            auto& app = Application::GetInstance();
            if (app.GetDeviceState() == kDeviceStateStarting && !WifiStation::GetInstance().IsConnected()) {
                ResetWifiConfiguration();
            }
            app.ToggleChatState(); });
        touch_button_.OnPressDown([this]()
                                  { Application::GetInstance().StartListening(); });
        touch_button_.OnPressUp([this]()
                                { Application::GetInstance().StopListening(); });

        volume_up_button_.OnClick([this]()
                                  {
            auto codec = GetAudioCodec();
            auto volume = codec->output_volume() + 10;
            if (volume > 100) {
                volume = 100;
            }
            codec->SetOutputVolume(volume);
            GetDisplay()->ShowNotification(Lang::Strings::VOLUME + std::to_string(volume)); });

        volume_up_button_.OnLongPress([this]()
                                      {
            GetAudioCodec()->SetOutputVolume(100);
            GetDisplay()->ShowNotification(Lang::Strings::MAX_VOLUME); });

        volume_down_button_.OnClick([this]()
                                    {
            auto codec = GetAudioCodec();
            auto volume = codec->output_volume() - 10;
            if (volume < 0) {
                volume = 0;
            }
            codec->SetOutputVolume(volume);
            GetDisplay()->ShowNotification(Lang::Strings::VOLUME + std::to_string(volume)); });

        volume_down_button_.OnLongPress([this]()
                                        {
            GetAudioCodec()->SetOutputVolume(0);
            GetDisplay()->ShowNotification(Lang::Strings::MUTED); });
    }

    // 物联网初始化，逐步迁移到 MCP 协议
    void InitializeTools()
    {
        static LampController lamp(LAMP_GPIO);
        static TrafficLightController traffic_light(RED_LED_GPIO, YELLOW_LED_GPIO, GREEN_LED_GPIO);
    }

public:
    CompactWifiBoard() : boot_button_(BOOT_BUTTON_GPIO),
                         touch_button_(TOUCH_BUTTON_GPIO),
                         volume_up_button_(VOLUME_UP_BUTTON_GPIO),
                         volume_down_button_(VOLUME_DOWN_BUTTON_GPIO)
    {
        InitializeDisplayI2c();
        InitializeSsd1306Display();
        InitializeButtons();
        InitializeTools();

        // Initialize the CircularStrip with GPIO and number of LEDs
        led_strip_ = new CircularStrip(BUILTIN_LED_GPIO, 4); //  LEDs in the strip
        led_strip_->SetBrightness(255, 4);                   // Increase brightness (default: 32, 4)
    }

    virtual ~CompactWifiBoard()
    {
        delete led_strip_;
    }

    virtual Led *GetLed() override
    {
        return led_strip_;
    }

    virtual AudioCodec *GetAudioCodec() override
    {
#ifdef AUDIO_I2S_METHOD_SIMPLEX
        static NoAudioCodecSimplex audio_codec(AUDIO_INPUT_SAMPLE_RATE, AUDIO_OUTPUT_SAMPLE_RATE,
                                               AUDIO_I2S_SPK_GPIO_BCLK, AUDIO_I2S_SPK_GPIO_LRCK, AUDIO_I2S_SPK_GPIO_DOUT, AUDIO_I2S_MIC_GPIO_SCK, AUDIO_I2S_MIC_GPIO_WS, AUDIO_I2S_MIC_GPIO_DIN);
#else
        static NoAudioCodecDuplex audio_codec(AUDIO_INPUT_SAMPLE_RATE, AUDIO_OUTPUT_SAMPLE_RATE,
                                              AUDIO_I2S_GPIO_BCLK, AUDIO_I2S_GPIO_WS, AUDIO_I2S_GPIO_DOUT, AUDIO_I2S_GPIO_DIN);
#endif
        return &audio_codec;
    }

    virtual Display *GetDisplay() override
    {
        return display_;
    }
};

DECLARE_BOARD(CompactWifiBoard);

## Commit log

2025-10-07 #CSM Hardware Config
    [16m.csv, 16m_c3.csv, 16m_custom_wakeword.csv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]
2025-11-10 Add TrafficLightController class for managing traffic light LEDs
2025-11-10 Refactor GPIO pin definitions for clarity and consistency in config.h
2025-11-12 Added CAD models, Schematics and BOM
    [Bottom-Enclosure.STL, ESP-AI-Assistant-BOM.xlsx, Middle-Enclosure.STL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]
2025-12-20 feat: Add KiCAD design files
    [AI voice assistant.kicad_pcb, AI voice assistant.kicad_sch]

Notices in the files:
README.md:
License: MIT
